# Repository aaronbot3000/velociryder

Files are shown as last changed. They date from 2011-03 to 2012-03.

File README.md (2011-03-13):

Velociryder Code
================

This is the software for the Velociryder, a self balancing two wheeled 
skateboard, started as a side project and was then entered in Georgia Tech's
2011 InVenture Prize. We made it all the way to the finals!

Features
--------

The code has the following features:
* PD control (no integral, wasn't necessary)
* Automatic startup via killswitch and level detection
* Support for foot pedal steering, just as in the Velociryder
* Use of accelerometer and gyroscope to obtain board level
* Moving average and complementary filters for the sensors

It works alright. 

Usage
-----
Things you will probably need to tweak:
### In velociryder.pde
* Turning constants

### In sensors.pde
* GYROTORAD4, GYROTORAD, ACCLTORAD: These convert the sensor's ADC units to 
	radians
* ACCL_CENTER: This defines the center balance point of the board
* sensor defines: The pins the sensors are on
* OHSHITSWITCH: killswitch pin

### In motors.pde
* However you control your motors

This is Arduino source code. So put it in a directory called velociryder in 
your sketchbook, fiddle, program, and go!

Implementations
---------------
* Version 1 of the Velociryder, back when it was called the Glide Board
http://www.youtube.com/watch?v=xvfUIxusPZw

* Version 2, built in aluminum and eliminated hand controller
http://www.gpb.org/inventure/velociryder

License
-------
This code is released under the MIT License. If you do use it, send me a 
message, I want to see it!

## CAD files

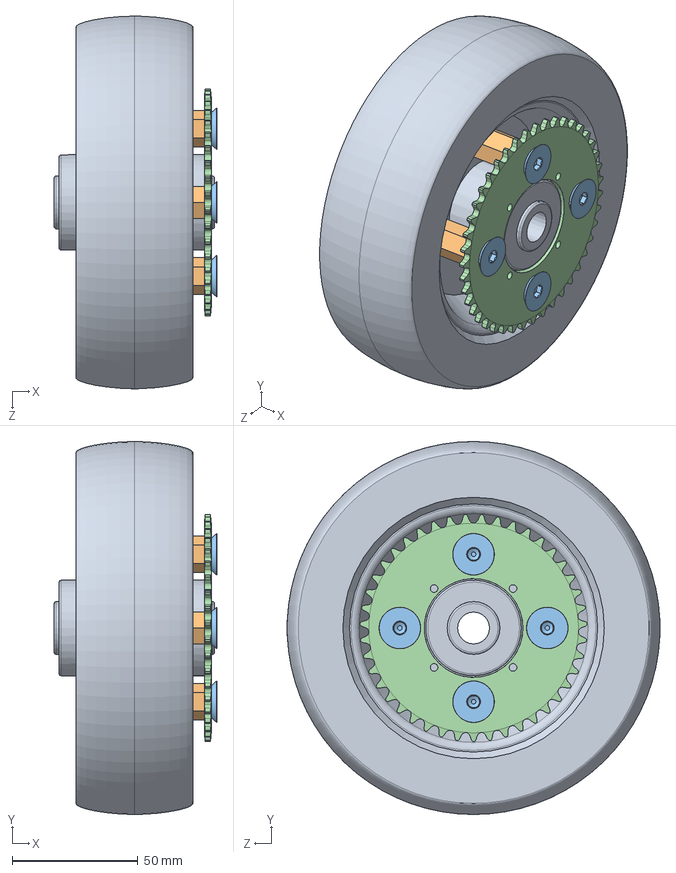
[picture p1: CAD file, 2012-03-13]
solidworks model/wheel-gear.sldasm
64.8 x 148.6 x 148.5 mm
wheel
wheel-standoff x 4
screw-wheel-2 x 4
sprocket-wheel-43

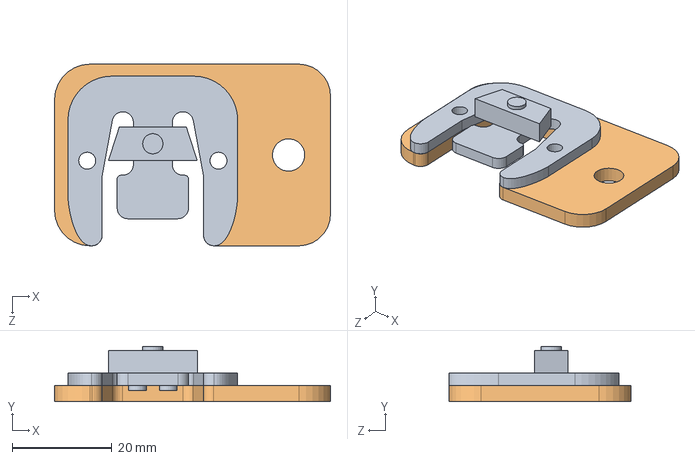
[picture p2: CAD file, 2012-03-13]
solidworks model/strain-gauge-assm.sldasm
55.2 x 11.0 x 36.4 mm
strain-gauge
strain-gauge.support

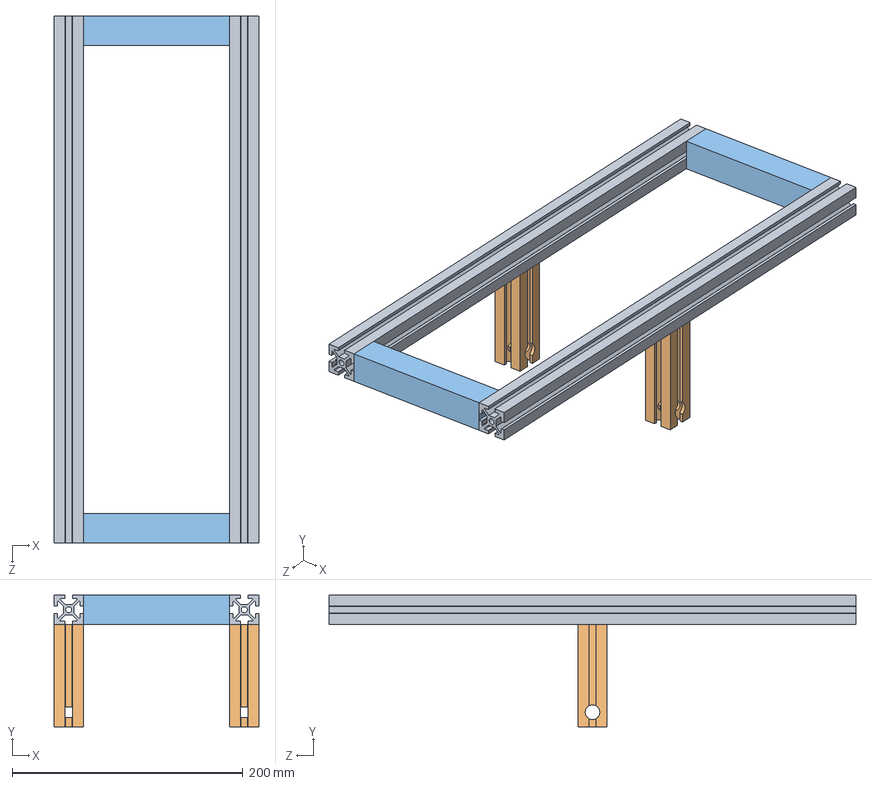
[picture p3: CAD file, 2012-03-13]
solidworks model/frame.sldasm
177.8 x 114.3 x 457.2 mm
8020-2ft x 2
8020-wheel_support x 2
8020-cross_support x 2

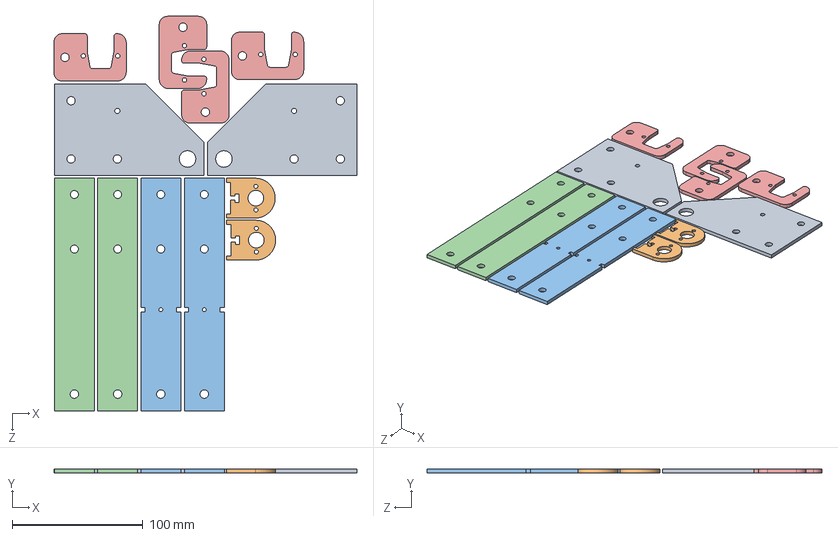
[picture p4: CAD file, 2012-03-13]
solidworks model/tocut_alum.sldasm
231.3 x 3.17 x 301.2 mm
encoder-mount x 2
encoder-support-1 x 2
motor-mount-p1 x 2
motor-mount-p2 x 2
strain-gauge.support x 4

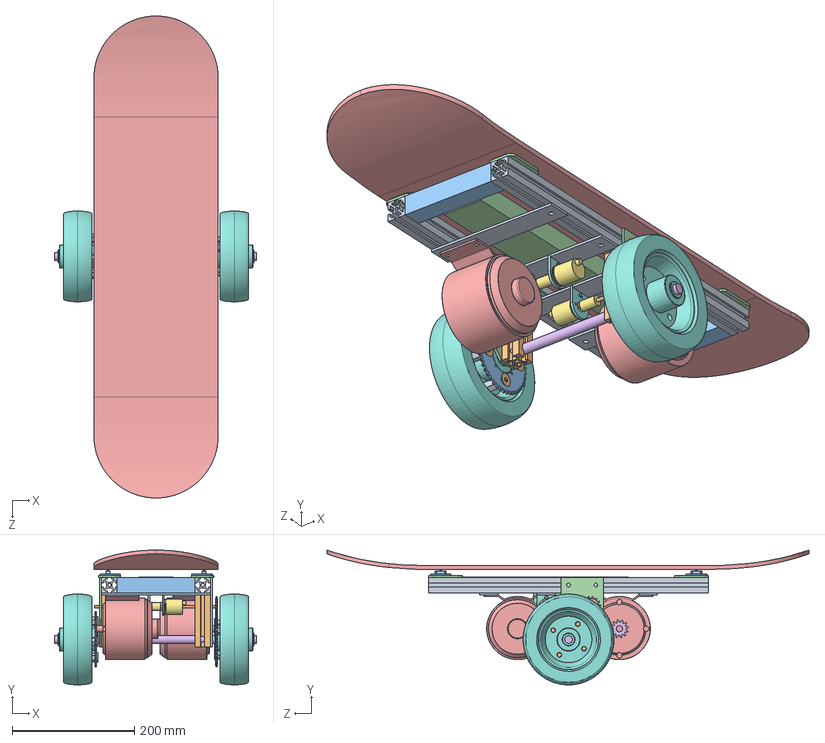
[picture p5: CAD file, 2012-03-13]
solidworks model/complete.sldasm
330.2 x 220.3 x 787.4 mm
8020-2ft x 2
8020-wheel_support x 2
8020-cross_support x 2
battery
axle
encoder x 2
wheel x 2
wheel-standoff x 8
screw-wheel-2 x 8
sprocket-wheel-43 x 2
encoder-mount x 2
scooter-motor x 2
sprocket-motor-12 x 2
shaft-coupler x 2
encoder-support-1 x 2
motor-mount x 2
encoder-shaft x 2
strain-gauge x 4
strain-gauge.support x 4
sprocket-15

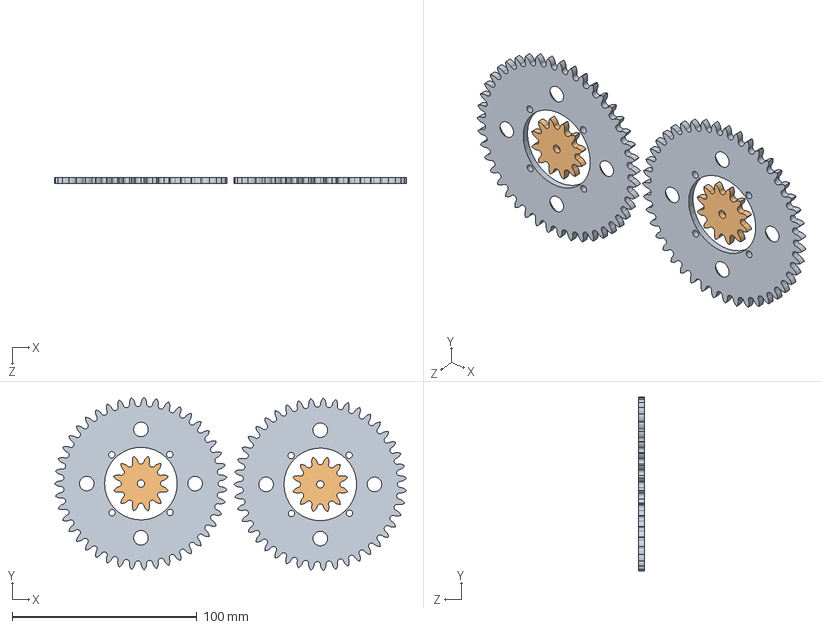
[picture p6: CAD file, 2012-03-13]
solidworks model/tocut_steel.SLDASM
190.8 x 94.0 x 3.17 mm
sprocket-wheel-40 x 2
sprocket-encoder-12 x 2

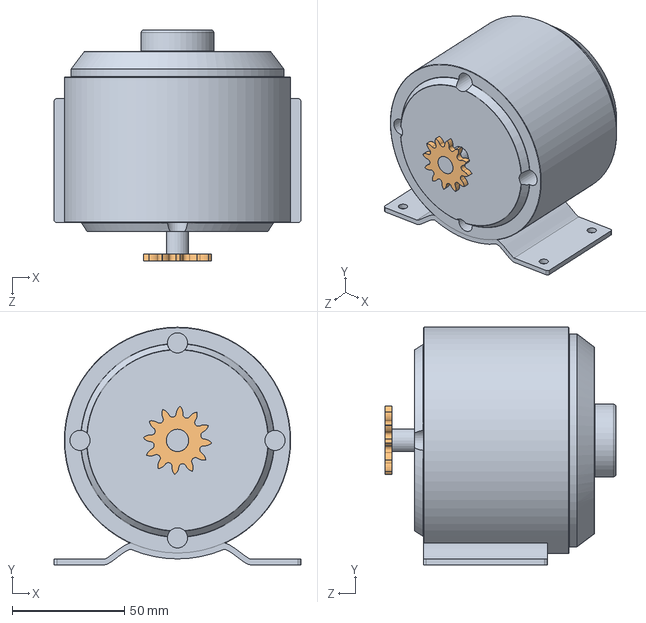
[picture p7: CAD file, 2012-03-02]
solidworks model/scooter-motor-sprocket.sldasm
110.2 x 106.0 x 103.2 mm
scooter-motor
sprocket-motor-12

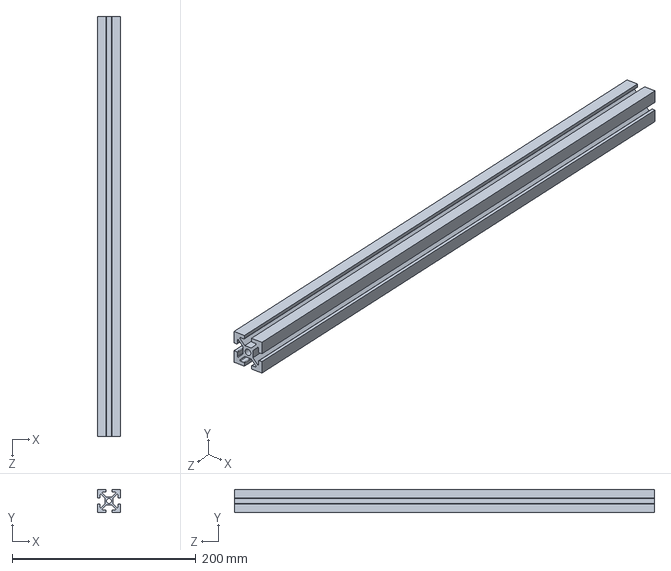
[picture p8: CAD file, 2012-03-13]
solidworks model/8020-2ft.sldprt
25.4 x 25.4 x 457.2 mm

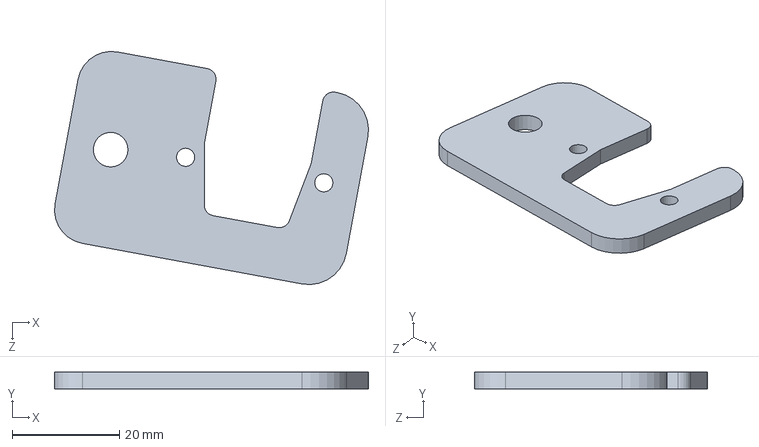
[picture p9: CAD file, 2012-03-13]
solidworks model/strain-gauge.support.sldprt
58.7 x 3.17 x 43.5 mm

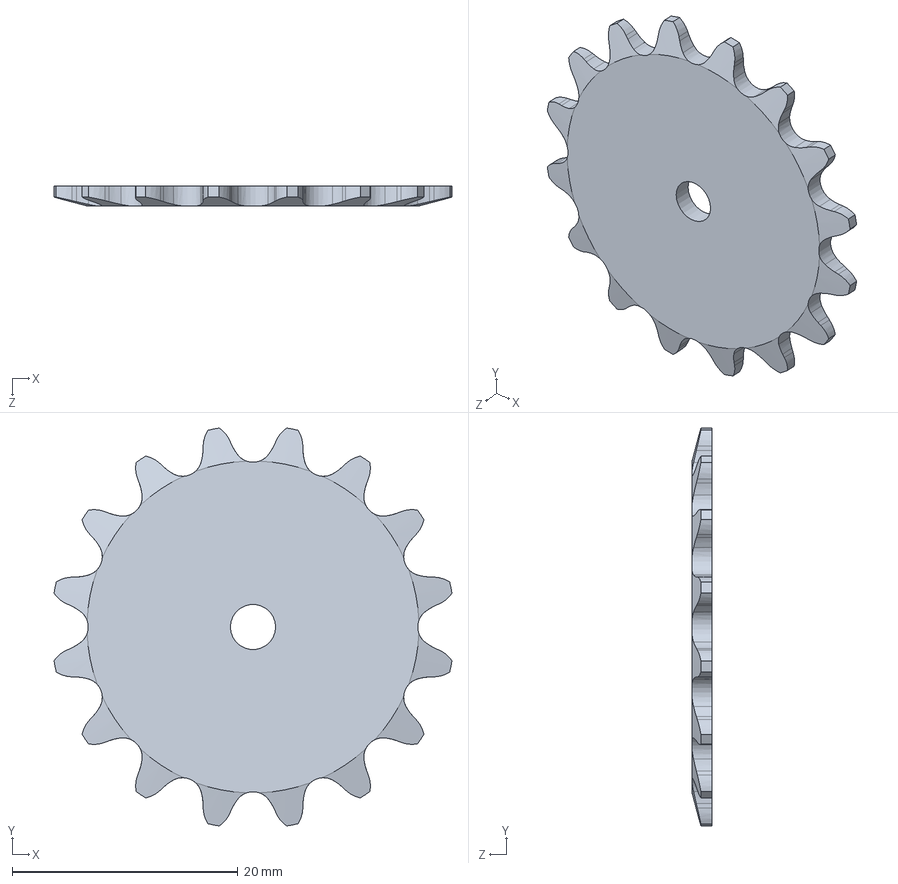
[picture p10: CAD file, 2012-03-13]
solidworks model/sprocket-16-cut.sldprt
35.2 x 35.2 x 1.78 mm

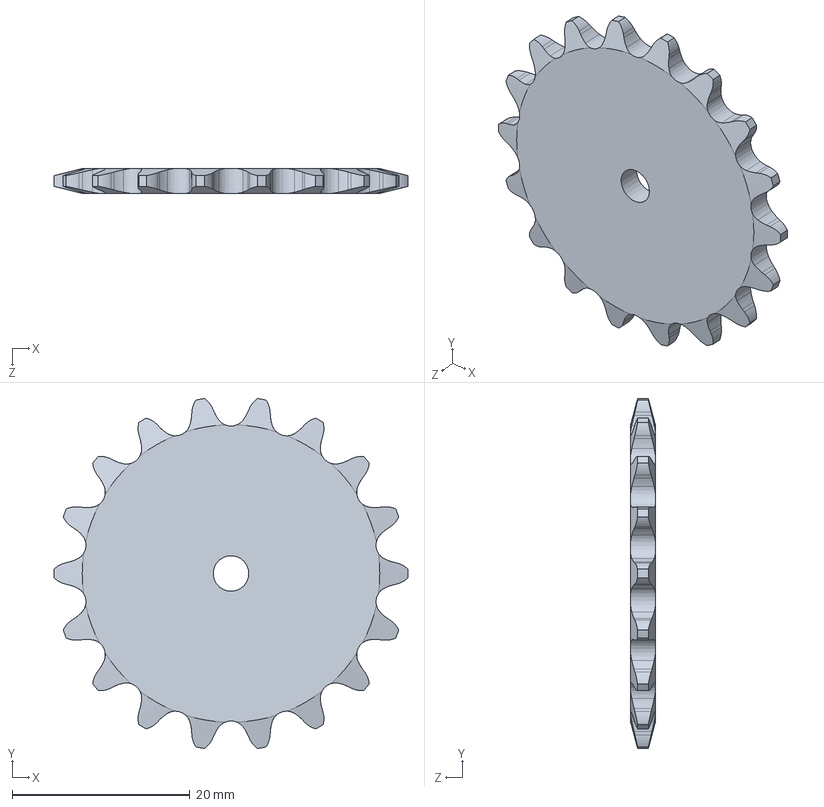
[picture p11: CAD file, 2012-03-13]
solidworks model/sprocket-18.SLDPRT
39.8 x 39.4 x 2.79 mm

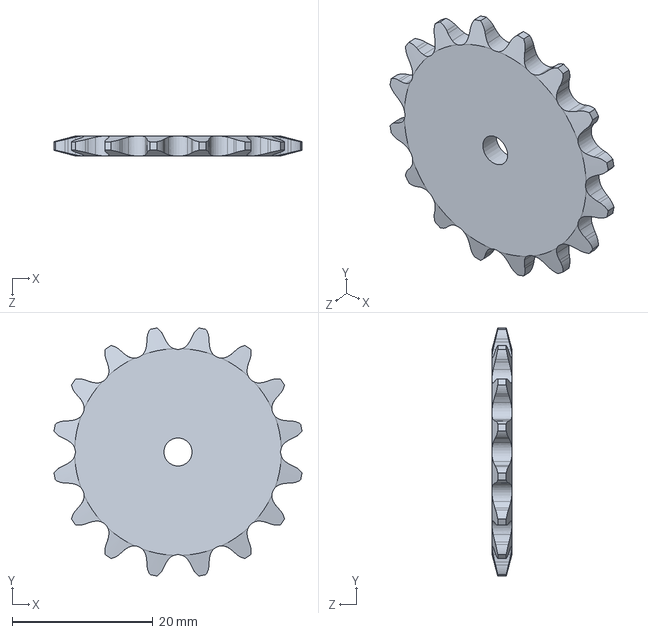
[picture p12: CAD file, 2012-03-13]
solidworks model/sprocket-16.sldprt
35.2 x 35.2 x 2.79 mm

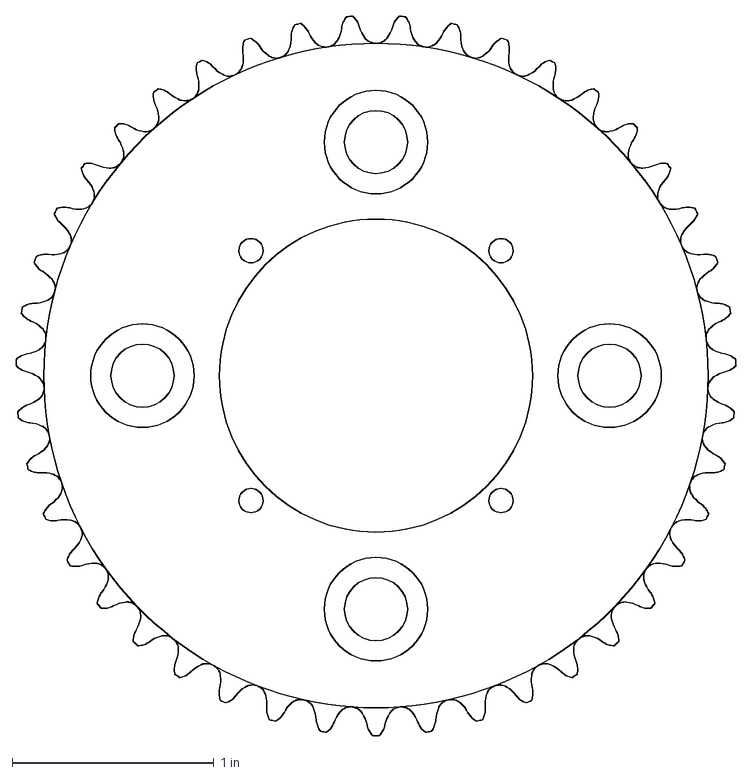
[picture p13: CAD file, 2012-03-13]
solidworks model/sprocket-43.dxf
3.56 x 3.56 in

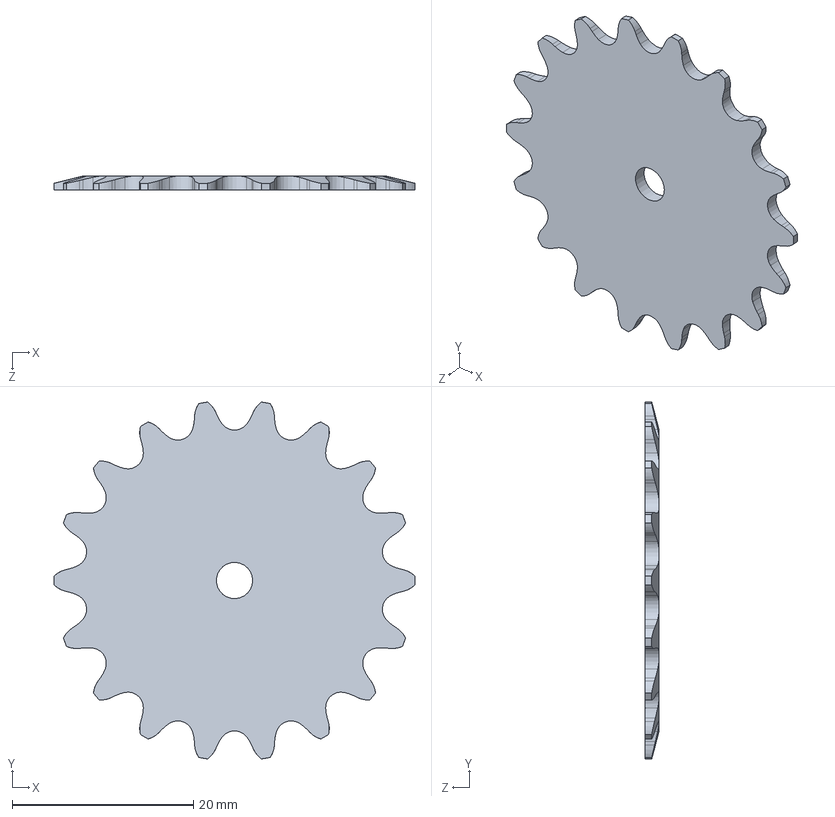
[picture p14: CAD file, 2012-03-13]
solidworks model/sprocket-18-half.sldprt
39.8 x 39.4 x 1.52 mm

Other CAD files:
solidworks model/strain-gauge-assm-mirror.sldasm
solidworks model/sprocket-encoder-12-new.sldprt
solidworks model/sprocket-wheel-43.sldprt
solidworks model/axle.sldprt
solidworks model/8020-cross_support.sldprt
solidworks model/8020-wheel_support.sldprt
solidworks model/CIM-motor.sldprt
solidworks model/battery.sldprt
solidworks model/deck.sldprt
solidworks model/encoder-mount.sldprt
solidworks model/encoder-shaft.sldprt
solidworks model/encoder-support-1.sldprt
solidworks model/encoder.sldprt
solidworks model/gear-encoder-18.sldprt
solidworks model/gear-motor-15.sldprt
solidworks model/gear-motor-18.sldprt
solidworks model/gear-wheel-56.sldprt
solidworks model/gear-wheel-64.sldprt
solidworks model/motor-mount-p1.sldprt
solidworks model/motor-mount-p2.sldprt
solidworks model/motor-mount.sldprt
solidworks model/scooter-motor.sldprt
solidworks model/screw-wheel-2.sldprt
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

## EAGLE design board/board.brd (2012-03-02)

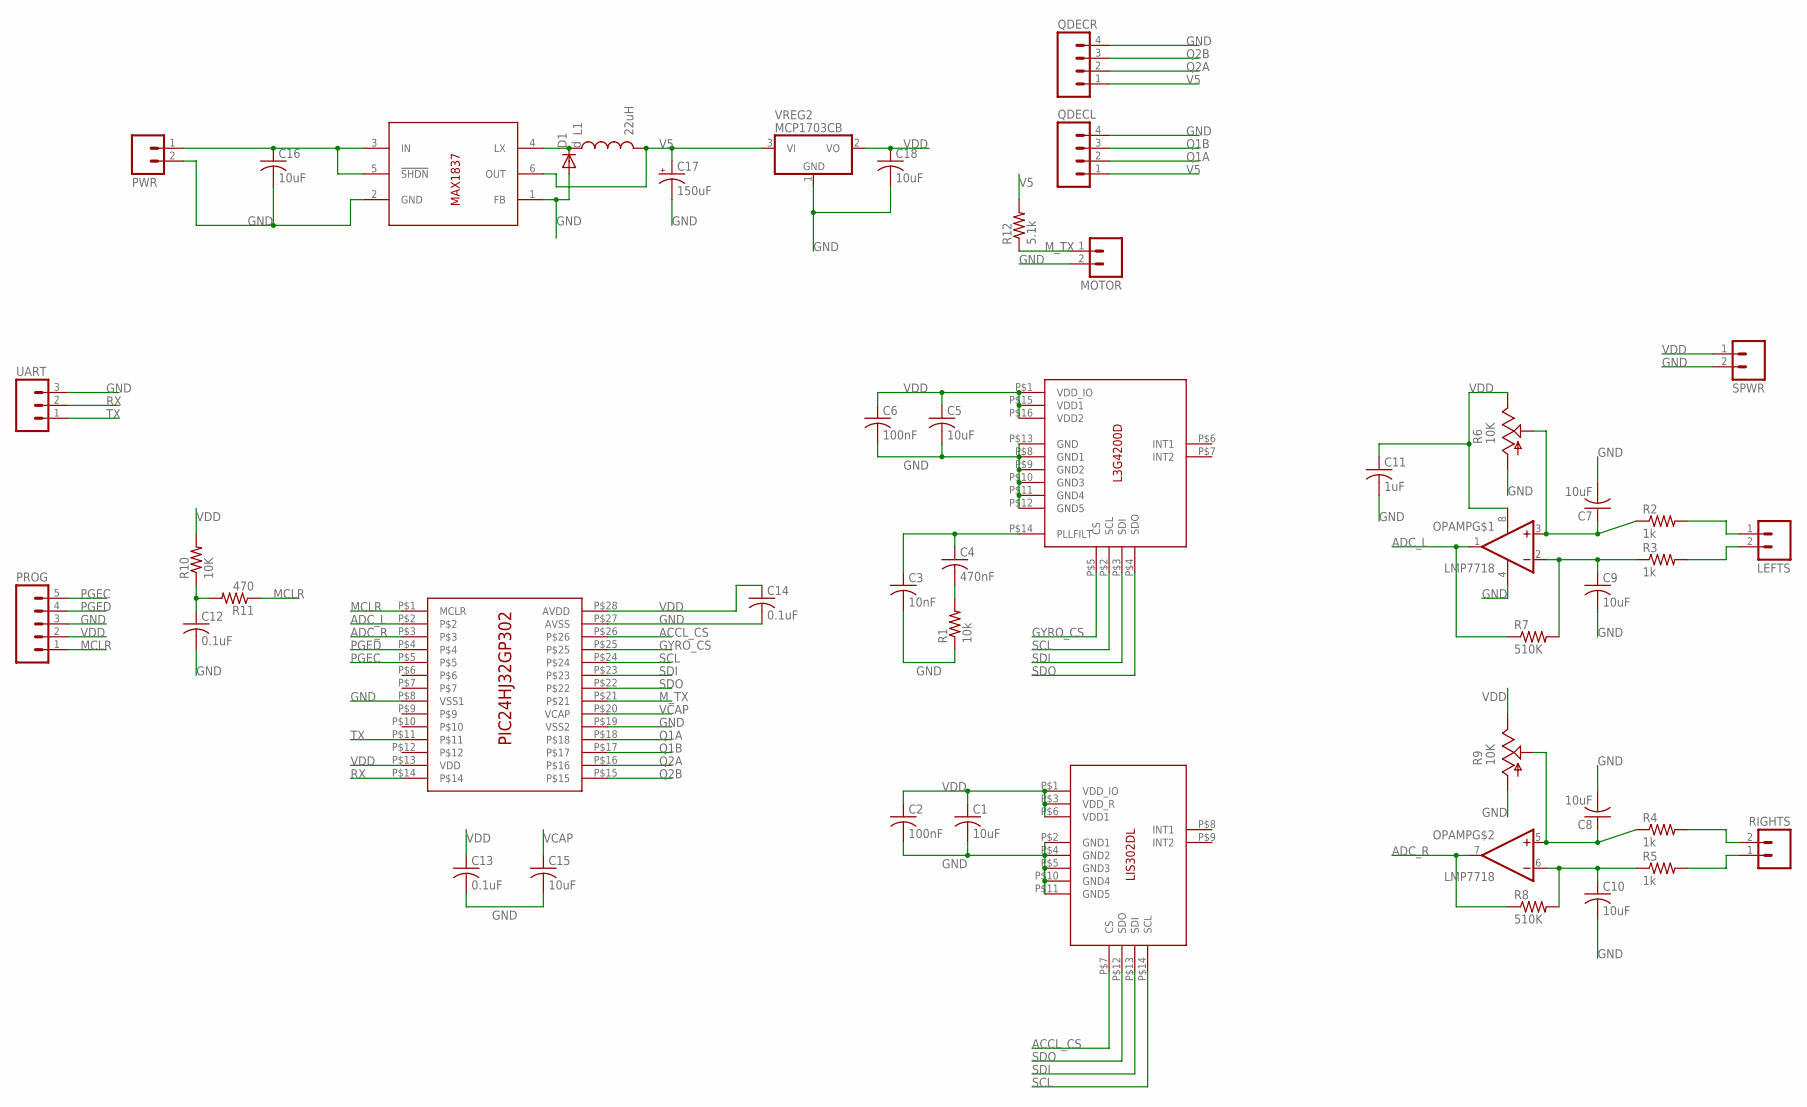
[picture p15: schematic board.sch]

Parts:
C1, C5, C15, C18: 10uF; C0805
C2, C6: 100nF; C0805
C3: 10nF; C0805
C4: 470nF; C0805
C7, C8, C9, C10, C16: 10uF; C1206
C11: 1uF; C0805
C12, C13, C14: 0.1uF; C0805
C17: 150uF; CT3528
D1: d; SOD-323
L1: 22uH; 1007
LEFTS: MOLEX-1X2
MOTOR: MOLEX-1X2
OPAMP: LMP7718; SO08
PROG: 1X05
PWR: MOLEX-1X2
QDECL: MOLEX-1X4
QDECR: MOLEX-1X4
R1: 10k; R0805
R2, R3, R4, R5: 1k; R1206
R6, R9: 10K; RJ6S
R7, R8: 510K; R0805
R10: 10K; R0805
R11: 470; R0805
R12: 5.1k; R0805
RIGHTS: MOLEX-1X2
SPWR: MOLEX-1X2
U$1: PIC24HJ32GP302; SOIC-28
U$2: L3G4200D; LGA-16
U$3: LIS302DL; LGA-14
UART: M03PTH; 1X03
VREG1: MAX1837; SOT23-6L
VREG2: MCP1703CB; SOT23

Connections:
ACCL_CS: U$1.P$26, U$3.P$7 (CS)
ADC_L: OPAMP.1 (OUT), R7.1, U$1.P$2
ADC_R: OPAMP.7 (OUT), R8.1, U$1.P$3
GND: C1.2, C2.2, C3.2, C5.2, C6.2, C7.2, C8.2, C9.2, C10.2, C11.2, C12.2, C13.2, C14.2, C15.2, C16.2, C17.-, C18.2, D1.2 (A), MOTOR.2, OPAMP.4 (V-), PROG.3, PWR.2, QDECL.4, QDECR.4, R1.1, R6.A, R9.A, SPWR.2, U$1.P$8 (VSS1), U$1.P$19 (VSS2), U$1.P$27 (AVSS), U$2.P$8 (GND1), U$2.P$9 (GND2), U$2.P$10 (GND3), U$2.P$11 (GND4), U$2.P$12 (GND5), U$2.P$13 (GND), U$3.P$2 (GND1), U$3.P$4 (GND2), U$3.P$5 (GND3), U$3.P$10 (GND4), U$3.P$11 (GND5), UART.3, VREG1.1 (FB), VREG1.2 (GND), VREG2.1 (GND)
GYRO_CS: U$1.P$25, U$2.P$5 (CS)
MCLR: PROG.1, R11.1, U$1.P$1 (MCLR)
M_TX: MOTOR.1, R12.1, U$1.P$21
unnamed: C16.1, PWR.1, VREG1.3 (IN), VREG1.5 (!SHDN)
unnamed: R4.2, RIGHTS.2
unnamed: C3.1, C4.1, U$2.P$14 (PLLFILT)
unnamed: C4.2, R1.2
unnamed: C7.1, OPAMP.3 (+IN), R2.1, R6.S
unnamed: C9.1, OPAMP.2 (-IN), R3.1, R7.2
unnamed: C10.1, OPAMP.6 (-IN), R5.1, R8.2
unnamed: LEFTS.1, R2.2
unnamed: LEFTS.2, R3.2
unnamed: R5.2, RIGHTS.1
unnamed: C8.1, OPAMP.5 (+IN), R4.1, R9.S
unnamed: D1.1 (C), L1.1, VREG1.4 (LX)
unnamed: C12.1, R10.1, R11.2
PGEC: PROG.5, U$1.P$5
PGED: PROG.4, U$1.P$4
Q1A: QDECL.2, U$1.P$18
Q1B: QDECL.3, U$1.P$17
Q2A: QDECR.2, U$1.P$16
Q2B: QDECR.3, U$1.P$15
RX: U$1.P$14, UART.2
SCL: U$1.P$24, U$2.P$2 (SCL), U$3.P$14 (SCL)
SDI: U$1.P$23, U$2.P$3 (SDI), U$3.P$13 (SDI)
SDO: U$1.P$22, U$2.P$4 (SDO), U$3.P$12 (SDO)
TX: U$1.P$11, UART.1
V5: C17.+, L1.2, QDECL.1, QDECR.1, R12.2, VREG1.6 (OUT), VREG2.3 (VI)
VCAP: C15.1, U$1.P$20 (VCAP)
VDD: C1.1, C2.1, C5.1, C6.1, C11.1, C13.1, C14.1, C18.1, OPAMP.8 (V+), PROG.2, R6.E, R9.E, R10.2, SPWR.1, U$1.P$13 (VDD), U$1.P$28 (AVDD), U$2.P$1 (VDD_IO), U$2.P$15 (VDD1), U$2.P$16 (VDD2), U$3.P$1 (VDD_IO), U$3.P$3 (VDD_R), U$3.P$6 (VDD1), VREG2.2 (VO)

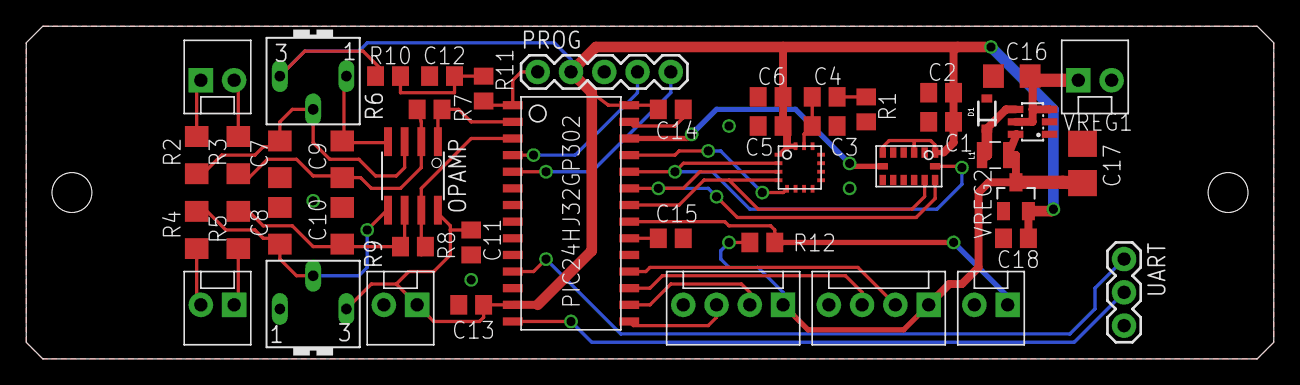
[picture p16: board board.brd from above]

Board: 2 copper layers, 95.2 x 25.4 mm, 47 parts (0 on the bottom side), 34 nets.

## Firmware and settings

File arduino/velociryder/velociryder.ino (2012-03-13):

/*
Copyright (C) 2011 by Aaron Fan

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
THE SOFTWARE IS PROVIDED "AS IS", WITHOUT WARRANTY OF ANY KIND, EXPRESS OR
IMPLIED, INCLUDING BUT NOT LIMITED TO THE WARRANTIES OF MERCHANTABILITY,
FITNESS FOR A PARTICULAR PURPOSE AND NONINFRINGEMENT. IN NO EVENT SHALL THE
AUTHORS OR COPYRIGHT HOLDERS BE LIABLE FOR ANY CLAIM, DAMAGES OR OTHER
LIABILITY, WHETHER IN AN ACTION OF CONTRACT, TORT OR OTHERWISE, ARISING FROM,
OUT OF OR IN CONNECTION WITH THE SOFTWARE OR THE USE OR OTHER DEALINGS IN
THE SOFTWARE.
*/


#include <SoftwareSerial.h>

#define OCCASIONALDEBUG

/*
   Front of board
   +100 power
   +degree


   -zGyro   +zGyro
   Motor1   Motor2


   -degree
   -100 power
 */
//+ = tip forward
//- = tip backward


// PID control constants
// Can change by around 5 at a time
#define PGAIN 650
#define DGAIN 450

#define P3MULT 135

#define LVL_AVG_LEN 8

// Other control constants
#define ACCL_MIX .008

// Turning constants
#define TURNPOT_MARGIN 28
#define STEER_OFFSET 0
#define STEER_GYRO_MARGIN 8
#define STEER_CORRECT_POWER .30
#define STEER_POWER .20
#define MIN_STEER 90

#ifdef OCCASIONALDEBUG
#define BAUD 57600
static uint8_t counter;
#endif

static uint8_t i, j;

static float steer_req;

static float ygyro4_ref;
static float ygyro_ref;
static float zgyro_ref;
static float turnpot_ref;

static float level;
static float angle = 0;

static bool wait_for_level = false;

extern float yaccl_filt;
extern float zaccl_filt;
extern float ygyro4_sum;
extern float ygyro_sum;
extern float zgyro_sum;
extern float turnpot_sum;

void setup() {
#ifdef OCCASIONALDEBUG
	Serial.begin(BAUD);
#endif

	init_sensors();
	init_motors();

	// Build up some previous values
	for (int i=0; i<200; i++) {
		run_magic();
	}

	// 5 seconds may seem long but it doesn't work too well unless its 5 seconds
	//delay (5000);

	read_ygyro4();
	read_ygyro();
	read_zgyro();

	ygyro4_ref = ygyro4_sum;
	ygyro_ref = ygyro_sum;
	zgyro_ref = zgyro_sum;

	// Wait for user to level board
	wait_for_level = true;


	// the turnpot's value at center is different when at rest and when stood on
	// So take the reference point after the user is on the board
	//read_turnpot();
	//turnpot_ref = turnpot_sum;

	level = 0;
	angle = 0;
}

/*
void process_steering() {
	float zgyro, steer;

	read_turnpot();
	steer = -(turnpot_sum - turnpot_ref);

	// If going straight
	if (abs(steer) <= TURNPOT_MARGIN) {
		read_zgyro();
		zgyro = (zgyro_sum - zgyro_ref);

		if (abs(zgyro) > STEER_GYRO_MARGIN)
			steer_req = STEER_CORRECT_POWER * zgyro;
		else
			steer_req = 0;
	}
	// We are turning
	else {
		if (steer < turnpot_ref)
			steer += STEER_OFFSET;
		else
			steer -= STEER_OFFSET;

		// Scale according to speed
		steer_req = steer * STEER_POWER ;//* ((-abs(level) * (1-MIN_STEER)/100) + 1);
	}
}
*/

float accl_angle;

void run_magic() {
	static float filt_level[LVL_AVG_LEN];
	static float sum;
	static int filt_ind;

	static float p_angle = 0;
	static unsigned long time = 0;

	float gyro;
	float time_since = 0;
	float avg = 0;

	p_angle = angle;

	time_since = (((float)(millis() - time))/1000.0);
	time = millis();

#ifdef OCCASIONALDEBUG
	if (counter == 0) {
		Serial.print("Time: ");
		Serial.println(time_since, 10);
	}
#endif

	read_ygyro4();
	read_yaccl();

	if (abs(ygyro4_sum - ygyro4_ref) < 1.5) {
		read_ygyro();
		gyro = (ygyro_sum - ygyro_ref) * time_since;
	}
	else {
		gyro = (ygyro4_sum - ygyro4_ref) * time_since;
	}

	//accl_angle = atan2(yaccl_filt - ACCL_CENTER, zaccl_filt - ACCL_CENTER);
	accl_angle = yaccl_filt;

	angle = ((angle + gyro) * (1 - ACCL_MIX)) + (accl_angle * ACCL_MIX);

	// P
	level = PGAIN * (P3MULT * angle * angle * angle + angle);

	// D
	level += DGAIN * (angle - p_angle);

	sum -= filt_level[filt_ind];
	filt_level[filt_ind] = level;
	sum += filt_level[filt_ind];

	filt_ind = (++filt_ind) % LVL_AVG_LEN;
	
	level = sum / LVL_AVG_LEN;
}

void set_motors()
{
	int16_t motorL = level + steer_req;
	int16_t motorR = level - steer_req;

	motorL = constrain(motorL, -100, 100);
	motorR = constrain(motorR, -100, 100);

	if (!read_shit_switch()) {
		kill_motors();
		wait_for_level = true;
	}

	else if (wait_for_level) {
		if (abs(level) < 10)
			wait_for_level = false;
	}

	else {
		send_motor_command(motorL, motorR);
	}

#ifdef OCCASIONALDEBUG
	printStatusToSerial();
#endif
}

void loop()
{
	run_magic();
	//process_steering();
	set_motors();

#ifdef OCCASIONALDEBUG
	counter++;
	counter%=64;
#endif
}

#ifdef OCCASIONALDEBUG
void printStatusToSerial()
{
	if (counter == 0)
	{
		Serial.println("=========");
		Serial.print("lvl: ");
		Serial.println(level);
		Serial.print("ang: ");
		Serial.println(angle);
		Serial.print("accl_angle: ");
		Serial.println(accl_angle);
		Serial.print("gyro4: ");
		Serial.println((ygyro4_sum - ygyro4_ref), 8);
		Serial.print("gyro: ");
		Serial.println((ygyro_sum - ygyro_ref), 8);
		Serial.print("yaccl: ");
		Serial.println(yaccl_filt);
		/*
		Serial.print("steer: ");
		Serial.println(turnpot_sum - turnpot_ref);
		Serial.print("steer_req: ");
		Serial.println(steer_req);
		*/
		Serial.print("wait level: ");
		Serial.println(wait_for_level);
		Serial.print("zgyro: ");
		Serial.println(zgyro_sum);
	}
}
#endif

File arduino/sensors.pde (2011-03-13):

/*
Copyright (C) 2011 by Aaron Fan

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
THE SOFTWARE IS PROVIDED "AS IS", WITHOUT WARRANTY OF ANY KIND, EXPRESS OR
IMPLIED, INCLUDING BUT NOT LIMITED TO THE WARRANTIES OF MERCHANTABILITY,
FITNESS FOR A PARTICULAR PURPOSE AND NONINFRINGEMENT. IN NO EVENT SHALL THE
AUTHORS OR COPYRIGHT HOLDERS BE LIABLE FOR ANY CLAIM, DAMAGES OR OTHER
LIABILITY, WHETHER IN AN ACTION OF CONTRACT, TORT OR OTHERWISE, ARISING FROM,
OUT OF OR IN CONNECTION WITH THE SOFTWARE OR THE USE OR OTHER DEALINGS IN
THE SOFTWARE.
*/

// TODO: Add balance point shift compensation for acceleration and 
// deceleration. Check by seeing change kn level

// Changeables
//#define OCCASIONALDEBUG

/*
   Front of board
   -100 power
   +degree


   -zGyro   +zGyro
   Motor1   Motor2


   -degree
   +100 power
 */

// Gyro constants
// 572.958 mV per rad per sec, 1.7453292 rad/sec max
#define GYROTORAD4 .005624596 // radians per second-unit
// 143 mV per deg per sec, 6.981317007975 rad/sec max
#define GYROTORAD   .02249838 // radians per second-unit

// 400 at 0.392 radians
#define ACCLTORAD .00392

// Accelerometer center point
#define ACCL_CENTER 500   // units

#define YACCL_AVG_LEN 8

// sensor defines
#define YGYRO 3
#define YGYRO4 4
#define ZGYRO 5
#define YACCL 1
#define ZACCL 2
#define TURNPOT 0

// input defines
#define OHSHITSWITCH 13

static uint8_t k;

float yaccl_filt;
float zaccl_filt;

float ygyro4_sum;
float ygyro_sum;
float zgyro_sum;
float turnpot_sum;

void init_sensors() {
	analogReference(EXTERNAL);
}

bool read_shit_switch() {
	return digitalRead(OHSHITSWITCH);
}

void read_yaccl() {
	static int filt_ind = 0;
	static float sum = 0;
	static float yacclsum = 0;
	static float yaccl_filt[YACCL_AVG_LEN];

	yacclsum = 0;
	for (k=0; k<8; k++) {
		yacclsum += analogRead(YACCL) - ACCL_CENTER;
	}
	yacclsum /= 8;

	sum -= yaccl_filt[filt_ind];
	yaccl_filt[filt_ind] = yacclsum;
	sum += yaccl_filt[filt_ind];

	filt_ind = (++filt_ind) % YACCL_AVG_LEN;

	yaccl_filt = sum / YACCL_AVG_LEN;
	yaccl_filt *= ACCLTORAD;
}

void read_zaccl() {
	static float zaccl_savgolay_filt[7];
	// S-G filter again
	for (k=0; k<6; k++)
		zaccl_savgolay_filt[k] = zaccl_savgolay_filt[k+1];
	zaccl_savgolay_filt[6] = analogRead(ZACCL);

	// Magic numbers!!!
	zaccl_filt = ((-2*zaccl_savgolay_filt[0]) + 
				 ( 3*zaccl_savgolay_filt[1]) + 
				 ( 6*zaccl_savgolay_filt[2]) + 
				 ( 7*zaccl_savgolay_filt[3]) + 
				 ( 6*zaccl_savgolay_filt[4]) + 
				 ( 3*zaccl_savgolay_filt[5]) + 
				 (-2*zaccl_savgolay_filt[6]))/21.0; 
}

void read_ygyro4() {
	ygyro4_sum = 0;
	for (k=0; k<8; k++) {
		ygyro4_sum += analogRead(YGYRO4);
	}
	ygyro4_sum = ygyro4_sum / 8 * GYROTORAD4;
}

void read_ygyro() {
	ygyro_sum = 0;
	for (k=0; k<8; k++) {
		ygyro_sum += analogRead(YGYRO);
	}
	ygyro_sum = ygyro_sum / 8 * GYROTORAD;
}

void read_zgyro() {
	zgyro_sum = 0;
	for (k=0; k<8; k++) {
		zgyro_sum += analogRead(ZGYRO);
	}
	zgyro_sum = zgyro_sum / 8;
}

void read_turnpot() {
	turnpot_sum = 0;
	for (k=0; k<8; k++) {
		turnpot_sum += analogRead(TURNPOT);
	}
	turnpot_sum = turnpot_sum / 8;
}

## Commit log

2010-12-11 Add motors.pde, made progress
2010-12-11 Change the PID controls to the previous gimped version
2011-01-17 Add steering
2011-01-18 Fix complementary filter and YGYRO selection
    [sensors.pde]
2011-02-16 Fix steering
2011-03-03 Switch to radians, get rid of this division by 7 nonsense
2011-03-05 lolololol gyro to rads was incorrect
2011-03-05 Switch back to using first order approximation for accl angle
2011-03-13 Switch to a moving average filter, and it works better
2011-03-13 Add license to file headers
    Also, renamed a variable in sensors
2012-01-23 Add solidworks models for v4
    [8020-2ft.sldprt, 8020-cross_support.sldprt, 8020-wheel_support.sldprt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]
2012-01-23 Add EAGLE CAD files
2012-01-23 move legacy arduino code to its own folder
2012-01-23 Continue work on the model
    [complete.SLDASM, gear-motor.sldprt, gear-wheel.sldprt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]
2012-01-24 Rename wheel gear, make wheel-gear assembly
    [gear-wheel-56.sldprt, gear-wheel.sldprt, wheel-gear.sldasm]
2012-01-24 Add rough axle
    [axle.sldprt]
2012-01-24 Rename gear-motor
    [gear-motor-15.sldprt]
2012-01-24 Add complete assembly and delete old gear-motor
    [complete.SLDASM, gear-motor.sldprt]
2012-01-24 New gears for new gear ratio and better sizes
    [gear-motor-18.sldprt, gear-wheel-64.sldprt]
2012-01-24 Fixing case sensitivity on Windows
    [axle.sldprt, complete.SLDASM]
2012-01-24 Final fix of Windows case insensitivity
    [axle.sldprt]
2012-01-24 Make the bore not stupid
    [gear-motor-18.sldprt, gear-wheel-64.sldprt]
2012-01-24 Make the frame its own assembly
    [complete.sldasm, frame.sldasm]
2012-01-24 Continue work
    [CIM-motor.sldprt, encoder.sldprt, motor-mount.sldprt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]
2012-02-11 Lots of work on the solidworks models. Mostly finished
    [8020-2ft.sldprt, 8020-cross_support.sldprt, 8020-wheel_support.sldprt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]
2012-02-11 Add controller board files
    [board.brd, board.sch]
2012-03-02 Finalize board.
    [board.brd, board.sch]
2012-03-02 Super solidworks update.
    [8020-2ft.sldprt, complete.sldasm, encoder-mount.sldprt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]
2012-03-02 Fix axle length
    [axle.sldprt, complete.sldasm]
2012-03-02 Add the rest of the strain gauges
    [complete.sldasm, strain-gauge-assm-mirror.sldasm]
2012-03-02 I think I did something
    [complete.sldasm]
2012-03-02 Rename machining prep file
    [tocut_alum.sldasm]

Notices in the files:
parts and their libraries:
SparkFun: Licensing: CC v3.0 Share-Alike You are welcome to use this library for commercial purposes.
